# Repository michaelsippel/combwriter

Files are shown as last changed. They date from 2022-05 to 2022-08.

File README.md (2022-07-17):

# Combwriter

Ergonomical Split-Typewriter with fully 3D-Printed Circuit Board and Hexagonal Keycaps

**Work-In-Progress Prototype**
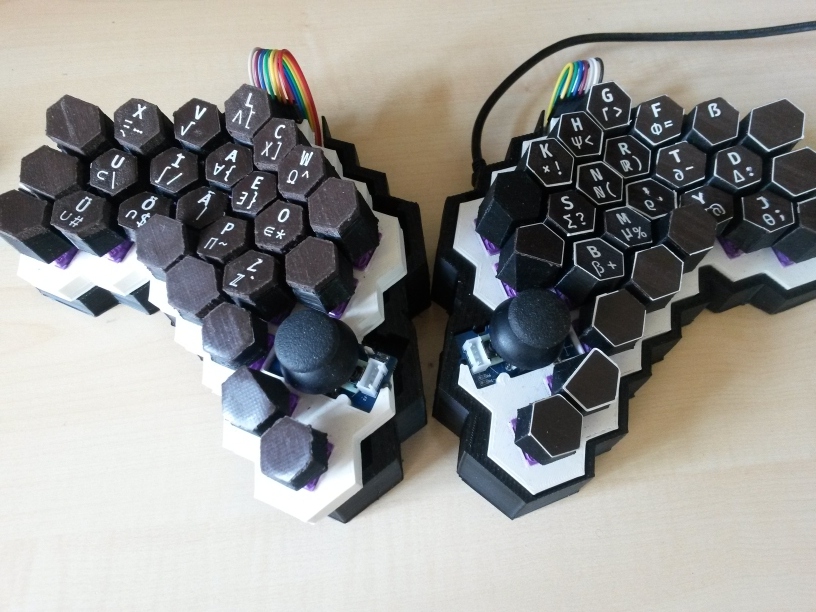
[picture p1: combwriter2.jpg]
Prototype


Build Process

## Features

* ergonomical split-layout
* hot-swappable, CherryMX compatible switches
* thumb joysticks for both hands
* 3D-printed hexagonal keycaps
* 3D-printed base-plate, including 3D-printed circuit board
* parametrized design:
  - customizable key-heights and angles ([layout.scad:21](https://github.com/michaelsippel/combwriter/blob/29c07f640cc59fc860c85ccadef08a7f6f34e77a/layout.scad#L21))
  - customizable key-symbols  ([layout.scad:35](https://github.com/michaelsippel/combwriter/blob/29c07f640cc59fc860c85ccadef08a7f6f34e77a/layout.scad#L35))

## Build it Yourself

### Materials

| Qty | Abstract |
|-----|---|
| 50  | Diode (general purpose, axial) |
| 50  | CherryMX Compatible Switch |
| 2 | Thumb Joystick |
| 2 | 7x1 Pin-Header (2.54mm) |
| 2 | 4x1 Pin-Header (2.54mm) |
| 1 | Filament; PLA White |
| 1 | Filament; PLA Black |
| 1 | Filament; PLA Wood (optional)  |
| 1 | Filament; TPU Conductive |

## Donate XMR

    83SyrAeLemHR6cqAort2PgAvSq9dUSR5VWPtDecGFGUvJibR3QRkqNfUNQ1kiWuCXr25yss1NfpG4VpMcH8K85dt7ptfVHk

## License

[GPLv3](COPYING)

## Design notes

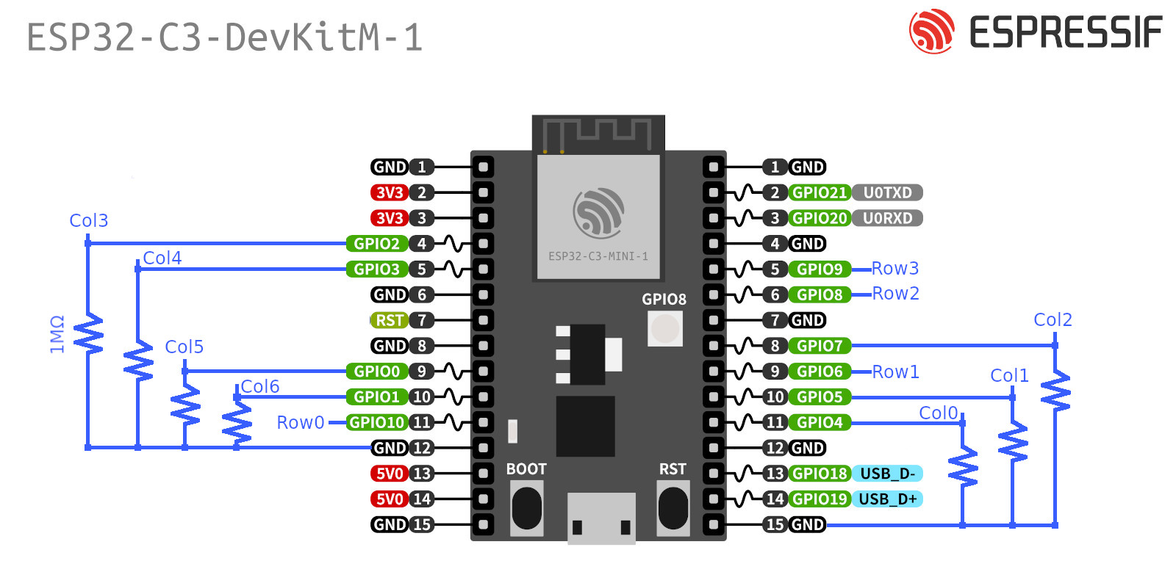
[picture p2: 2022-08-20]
esp32c3-devkit-pinout.jpg

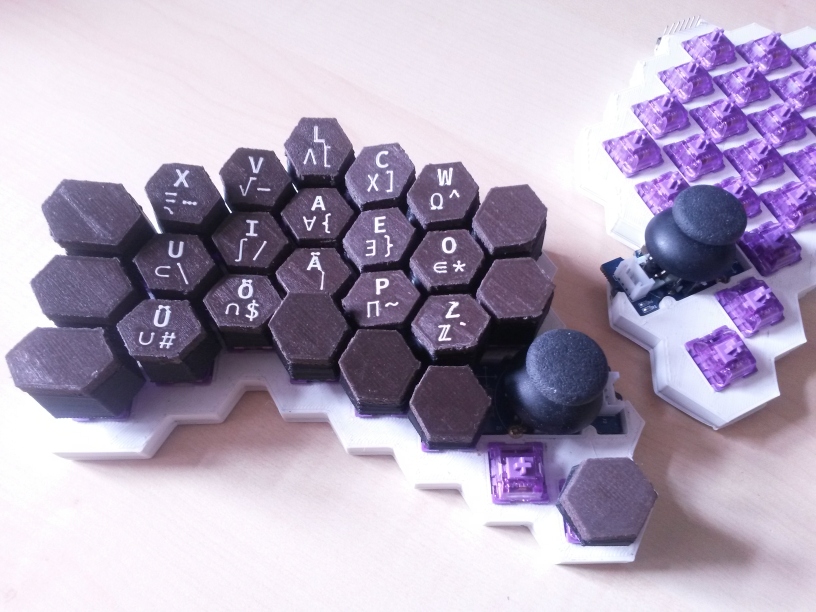
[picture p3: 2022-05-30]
combwriter.jpg

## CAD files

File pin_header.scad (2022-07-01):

/*
      Copyright 2022 Michael Sippel

<<<<>>>><<>><><<>><<<*>>><<>><><<>><<<<>>>>

 This program is free software: you can redistribute it and/or modify it under the terms of the GNU General Public
 License as published by the Free Software Foundation, either version 3 of the License, or (at your option) any later
 version.

 This program is distributed in the hope that it will be useful, but WITHOUT ANY WARRANTY; without even the implied
 warranty of MERCHANTABILITY or FITNESS FOR A PARTICULAR PURPOSE. See the GNU General Public License for more
 details.

 You should have received a copy of the GNU General Public License along with this program. If not, see
 <https://www.gnu.org/licenses/>.
*/

module pin_header(n=7, off=pin_off) {
  for(x = [0:(n-1)]) {

    translate([x*off, 0, 1.8])
      cube([1.5, 1.5, 12], center=true);

    translate([x*off, 0, 0])
      cube([2.6, 2.75, 2.5], center=true);

    translate([x*off, 0, 4+1.25])
      cube([2.66, 2.75, 8 ], center=true);
  }
}

module pin_headers(s) {
  translate([-8.7, 72.6, -5.5])
    pin_header(7);

mirror([max(-s,0), 0, 0])
  translate([-74.6,8.5,-5])
    rotate([0,0,-60])
    pin_header(4);
}

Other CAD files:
proto_board.scad
solids/src/keycaps/proto_board.scad
solids/src/stencils/pin_header.scad
caps.scad
diode.scad
keycap_base.scad
layout.scad
matrix_left.scad
matrix_right.scad
plateR_1_bot.scad
plateR_2_col.scad
plateR_3_mid.scad
plateR_4_row.scad
plateR_5_top1.scad
plateR_6_top2.scad
print_keycaps.scad
solids/src/case/case.scad
solids/src/keycaps/1_text.scad
solids/src/keycaps/2_top.scad
solids/src/keycaps/3_body.scad
solids/src/keycaps/base.scad
solids/src/layout/layout.scad
solids/src/layout/positions.scad
solids/src/layout/text/neo.scad
solids/src/plate/1_bot.scad
solids/src/plate/2_col.scad
solids/src/plate/3_mid.scad
solids/src/plate/4_row.scad
solids/src/plate/5_top1.scad
solids/src/plate/6_top2.scad
solids/src/plate/preview.scad
solids/src/stencils/connectors.scad
solids/src/stencils/diode.scad
solids/src/stencils/joystick.scad
solids/src/stencils/matrix_left.scad
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

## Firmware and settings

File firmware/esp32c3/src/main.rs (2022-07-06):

/*
      Copyright 2022 Michael Sippel

<<<<>>>><<>><><<>><<<*>>><<>><><<>><<<<>>>>

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
 You should have received a copy of the GNU General Public License along with this program. If not, see
 <https://www.gnu.org/licenses/>.
*/

#![no_std]
#![no_main]

#[macro_use]
mod scan_key;

#[macro_use]
#[allow(unused_macros)]
mod rowscanner;

#[macro_use]
#[allow(unused_macros)]
mod colscanner;

use combwriter_protocol::{
    ScanCode, KeyState, KeyPosition, Part
};


use core::fmt::Write;

use esp32c3_hal::{pac::Peripherals, prelude::*, RtcCntl, Serial, Timer, IO, clock::ClockControl};
use nb::block;
use panic_halt as _;
use riscv_rt::entry;

#[entry]
fn main() -> ! {
    let peripherals = Peripherals::take().unwrap();
    let system = peripherals.SYSTEM.split();
    let clocks = ClockControl::boot_defaults(system.clock_control).freeze();

    let mut rtc_cntl = RtcCntl::new(peripherals.RTC_CNTL);
    let mut serial0 = Serial::new(peripherals.UART0).unwrap();
    let mut timer0 = Timer::new(peripherals.TIMG0, clocks.apb_clock);
    let mut timer1 = Timer::new(peripherals.TIMG1, clocks.apb_clock);

    // Disable watchdog timers
    rtc_cntl.set_super_wdt_enable(false);
    rtc_cntl.set_wdt_enable(false);
    timer0.disable();
    timer1.disable();

    timer0.start(50u64.micros());
    
    let io = IO::new(peripherals.GPIO, peripherals.IO_MUX);
    rowscanner!(io, timer0, serial0, combwriter_protocol::Part::Right);
}

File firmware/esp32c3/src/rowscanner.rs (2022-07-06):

/*
      Copyright 2022 Michael Sippel

<<<<>>>><<>><><<>><<<*>>><<>><><<>><<<<>>>>

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
 You should have received a copy of the GNU General Public License along with this program. If not, see
 <https://www.gnu.org/licenses/>.
*/

use combwriter_protocol::{
    ScanCode, KeyState, KeyPosition, Part
};

macro_rules! scan_row {
    (
        $part:expr, $y:expr,
        $count:ident, $state:ident,
        $r:ident, $c0:ident, $c1:ident, $c2:ident, $c3:ident, $c4:ident, $c5:ident, $c6:ident,
        $serial:ident, $timer:ident
    ) => {

        $r.set_high().unwrap();
        block!($timer.wait()).unwrap();

        scan_key!($c0, 0, $y, $part, $count, $state, $serial);
        scan_key!($c1, 1, $y, $part, $count, $state, $serial);
        scan_key!($c2, 2, $y, $part, $count, $state, $serial);
        scan_key!($c3, 3, $y, $part, $count, $state, $serial);
        scan_key!($c4, 4, $y, $part, $count, $state, $serial);
        scan_key!($c5, 5, $y, $part, $count, $state, $serial);
        scan_key!($c6, 6, $y, $part, $count, $state, $serial);

        $r.set_low().unwrap();
        block!($timer.wait()).unwrap();
    }
}

macro_rules! rowscanner {
    ($io:ident, $timer0: ident, $serial0: ident, $part: expr) =>
    {
        let mut count = [0; 4*7];
        let mut state = [false; 4*7];

        let col0 = $io.pins.gpio4.into_floating_input();
        let col1 = $io.pins.gpio5.into_floating_input();
        let col2 = $io.pins.gpio7.into_floating_input();
        let col3 = $io.pins.gpio2.into_floating_input();
        let col4 = $io.pins.gpio3.into_floating_input();
        let col5 = $io.pins.gpio0.into_floating_input();
        let col6 = $io.pins.gpio1.into_floating_input();

        let mut row0 = $io.pins.gpio10.into_push_pull_output();
        let mut row1 = $io.pins.gpio6.into_push_pull_output();
        let mut row2 = $io.pins.gpio8.into_push_pull_output();
        let mut row3 = $io.pins.gpio9.into_push_pull_output();

        block!($timer0.wait()).unwrap();

        loop {
            scan_row!(
                $part, 0,
                count, state,
                row0, col0, col1, col2, col3, col4, col5, col6,
                $serial0, $timer0
            );
            scan_row!(
                $part, 1,
                count, state,
                row1, col0, col1, col2, col3, col4, col5, col6,
                $serial0, $timer0
            );
            scan_row!(
                $part, 2,
                count, state,
                row2, col0, col1, col2, col3, col4, col5, col6,
                $serial0, $timer0
            );
            scan_row!(
                $part, 3,
                count, state,
                row3, col0, col1, col2, col3, col4, col5, col6,
                $serial0, $timer0
            );
        }
    }
}

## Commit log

2022-04-06 first scad model for keycaps prototype
    [caps.scad]
2022-04-07 add height&angle maps and streched pinky keys
    [caps.scad]
2022-04-07 some ergonomical adjustments
    [caps.scad]
2022-04-07 add module for printing keycap set
    [caps.scad]
2022-04-08 stencil model for MX Switch & fix dimensions
    [caps.scad, mx_switch.scad]
2022-04-08 split files
    [keycap_base.scad, layout.scad, print_keycaps.scad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]
2022-04-14 fix x_stretch for right side
    [layout.scad]
2022-04-14 first model of connection matrix
    [print_plate.scad]
2022-04-14 add symbols on keycaps
    [keycap_base.scad, layout.scad, print_keycaps.scad]
2022-04-15 small adjustments in mx-switch stencil
    [mx_switch.scad]
2022-04-15 add missing connections for thumb keys
    [layout.scad, print_plate.scad]
2022-04-16 improve connection matrix
    [print_plate.scad]
2022-04-18 add diodes
    [diode.scad, print_plate.scad]
2022-04-24 add pin headers
    [diode.scad, print_plate.scad]
2022-04-28 improve symbols
    [keycap_base.scad, layout.scad]
2022-04-28 add joystick
    [layout.scad, print_plate.scad]
2022-05-01 make some traces a bit lighter for better printability
    [print_plate.scad]
2022-05-10 refactor code & enable right half except for traces
    [keycap_base.scad, layout.scad, print_keycaps.scad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]
2022-05-12 matrix connection for right half
    [connectors.scad, diode.scad, matrix_left.scad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]
2022-05-22 add makefile
    [plateR_1_bot.scad, plateR_2_col.scad, plateR_3_mid.scad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]
2022-05-22 small tweaks for better printability
    [diode.scad, matrix_left.scad, matrix_right.scad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]
2022-05-30 add gpl license
    [connectors.scad, diode.scad, keycap_base.scad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]
2022-05-30 README: feature list, BOM, donate address
2022-06-20 cutoff keycaps near joystick
    [layout.scad]
2022-06-29 first firmware prototype
2022-07-01 slightly more space for joystick
    [layout.scad, matrix_right.scad, plateR_3_mid.scad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]
2022-07-01 make traces thinner to avoid unwanted connections
    [diode.scad, matrix_right.scad, pin_header.scad]
2022-07-05 restructure file tree
    [1_bot.scad, 1_text.scad, 2_col.scad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]
2022-07-05 firmware-esp32c3: add rowscanner
2022-07-06 improve neo-symbols
    [neo.scad]
2022-07-06 add case
    [case.scad, positions.scad]
2022-07-07 extend the dirty driver hack
2022-07-08 ydotool driver: support shift-combinations
2022-07-12 improve case
    [case.scad]
2022-08-20 add pinout schematic for esp32c3 devkit
2022-08-21 case: reduce height and remove angles
    [case.scad]
2022-08-21 driver: fix baudrate setting
    [main.rs]
2022-08-25 driver: use uinput
2022-08-25 fix release events of simulated key-sequences
    [main.rs]
